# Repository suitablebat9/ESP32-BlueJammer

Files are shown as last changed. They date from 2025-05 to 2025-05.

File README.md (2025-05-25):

# ESP32-BlueJammer

**Bluetooth / BLE / WiFi / 2.4GHz Jamming Board**

The **ESP32-BlueJammer** is a compact, feature-rich board designed to disrupt devices operating on the 2.4GHz frequency band. Powered by an ESP32 and an nRF24 module, it generates noise and sends excessive packets to interfere with:

- Bluetooth audio and data connections  
- WiFi networks  
- BLE (Bluetooth Low Energy) devices  
- RC drones and remotes  
- IoT gadgets and more

> ⚠️ **Disclaimer:** This project is based entirely on the work of [Emensta](https://github.com/EmenstaNougat/ESP32-BlueJammer). I created this PCB to make their project more plug-and-play. All credit for the original firmware and research goes to them.

---

## 🔧 Features

- Toggleable on/off switch  
- Onboard momentary activation button  
- **`EXT Switch`** solder pads for external or wireless switch activation  
- **`EXT Power`** solder pads for external 5V power input  
  - (Polarity: **Left = GND**, **Right = 5V** with antennas facing away from you)  
- Combo firmware support – press the ESP32’s boot button while powered to cycle modes  
- **Blue jamming LED** shows active mode (can be disabled via jumper)  
- PH 2.0 battery connector (battery not included, connector provided)  
- USB Type-C power input on the board (not on the ESP32 directly)

---

## 🔄 LED Blink Mode Key

The **blue jamming LED** will blink to indicate the current active jamming mode on combo firmware:

- `1 blink` = **BT** (Bluetooth Classic)  
- `2 blinks` = **BLE** (Bluetooth Low Energy)  
- `3 blinks` = **WiFi**  
- `4 blinks` = **RC** (2.4GHz Drone/Remote)

The blink key is also printed on the right side of the board for quick reference.

---

## 🛰️ Mode Descriptions

| Mode | Description | Frequency Range |
|---|---|---|
| **BT 80CH** | Bluetooth Classic Jammer | 2.402 – 2.480 GHz |
| **BLE 40CH** | Bluetooth Low Energy Jammer | 2.400 – 2.4835 GHz |
| **BT-BLE 40-80CH** | Classic BT + BLE Combo Jammer | 2.400 – 2.4835 GHz |
| **BT-WiFi 14-80CH**| Classic BT + WiFi Combo Jammer | 2.400 – 2.4835 GHz |
| **WiFi 14CH** | WiFi Jammer | 2.400 – 2.4835 GHz |
| **2.4GHz All** | RC / Drone Jammer (CH 1–125) | 2.400 – 2.525 GHz |

---

## 🔌 Flashing the Firmware

You can easily flash your board using the browser-based [ESP32 BlueJammer Web Flasher](https://esp32-bluejammerflasher.pages.dev/) provided by Emensta.

### Steps:
1. Visit [ESP32-BlueJammerFlasher](https://esp32-bluejammerflasher.pages.dev/)
2. Choose the firmware type, "Generic"
3. Choose the firmware you want to flash
4. Connect your ESP32 via a data USB cable
5. Flash the firmware of your choice

> 💡 Tip: If flashing fails, make sure you’re using a data-capable USB cable and have the correct drivers installed for your ESP32.

---

## 🛒 Buy the Board

Want a fully assembled board? You can purchase one from my Tindie store here:  
👉 [PCB Studios on Tindie](https://www.tindie.com/products/pcb-studios/esp32-bluejammer/)

---

## 📦 What's Included

- Fully assembled **ESP32-BlueJammer PCB**
- PH 2.0 battery connector pre-installed
- Matching PH 2.0 connector for your battery (DIY soldering)
- Gerber files and schematic PDF (in this repo)

---

## ⚠️ Legal Notice

This project is for educational purposes only. Do not use this board to interfere with any wireless communications unless you have permission and are operating in a controlled, legal environment. You are solely responsible for what you do with this device.

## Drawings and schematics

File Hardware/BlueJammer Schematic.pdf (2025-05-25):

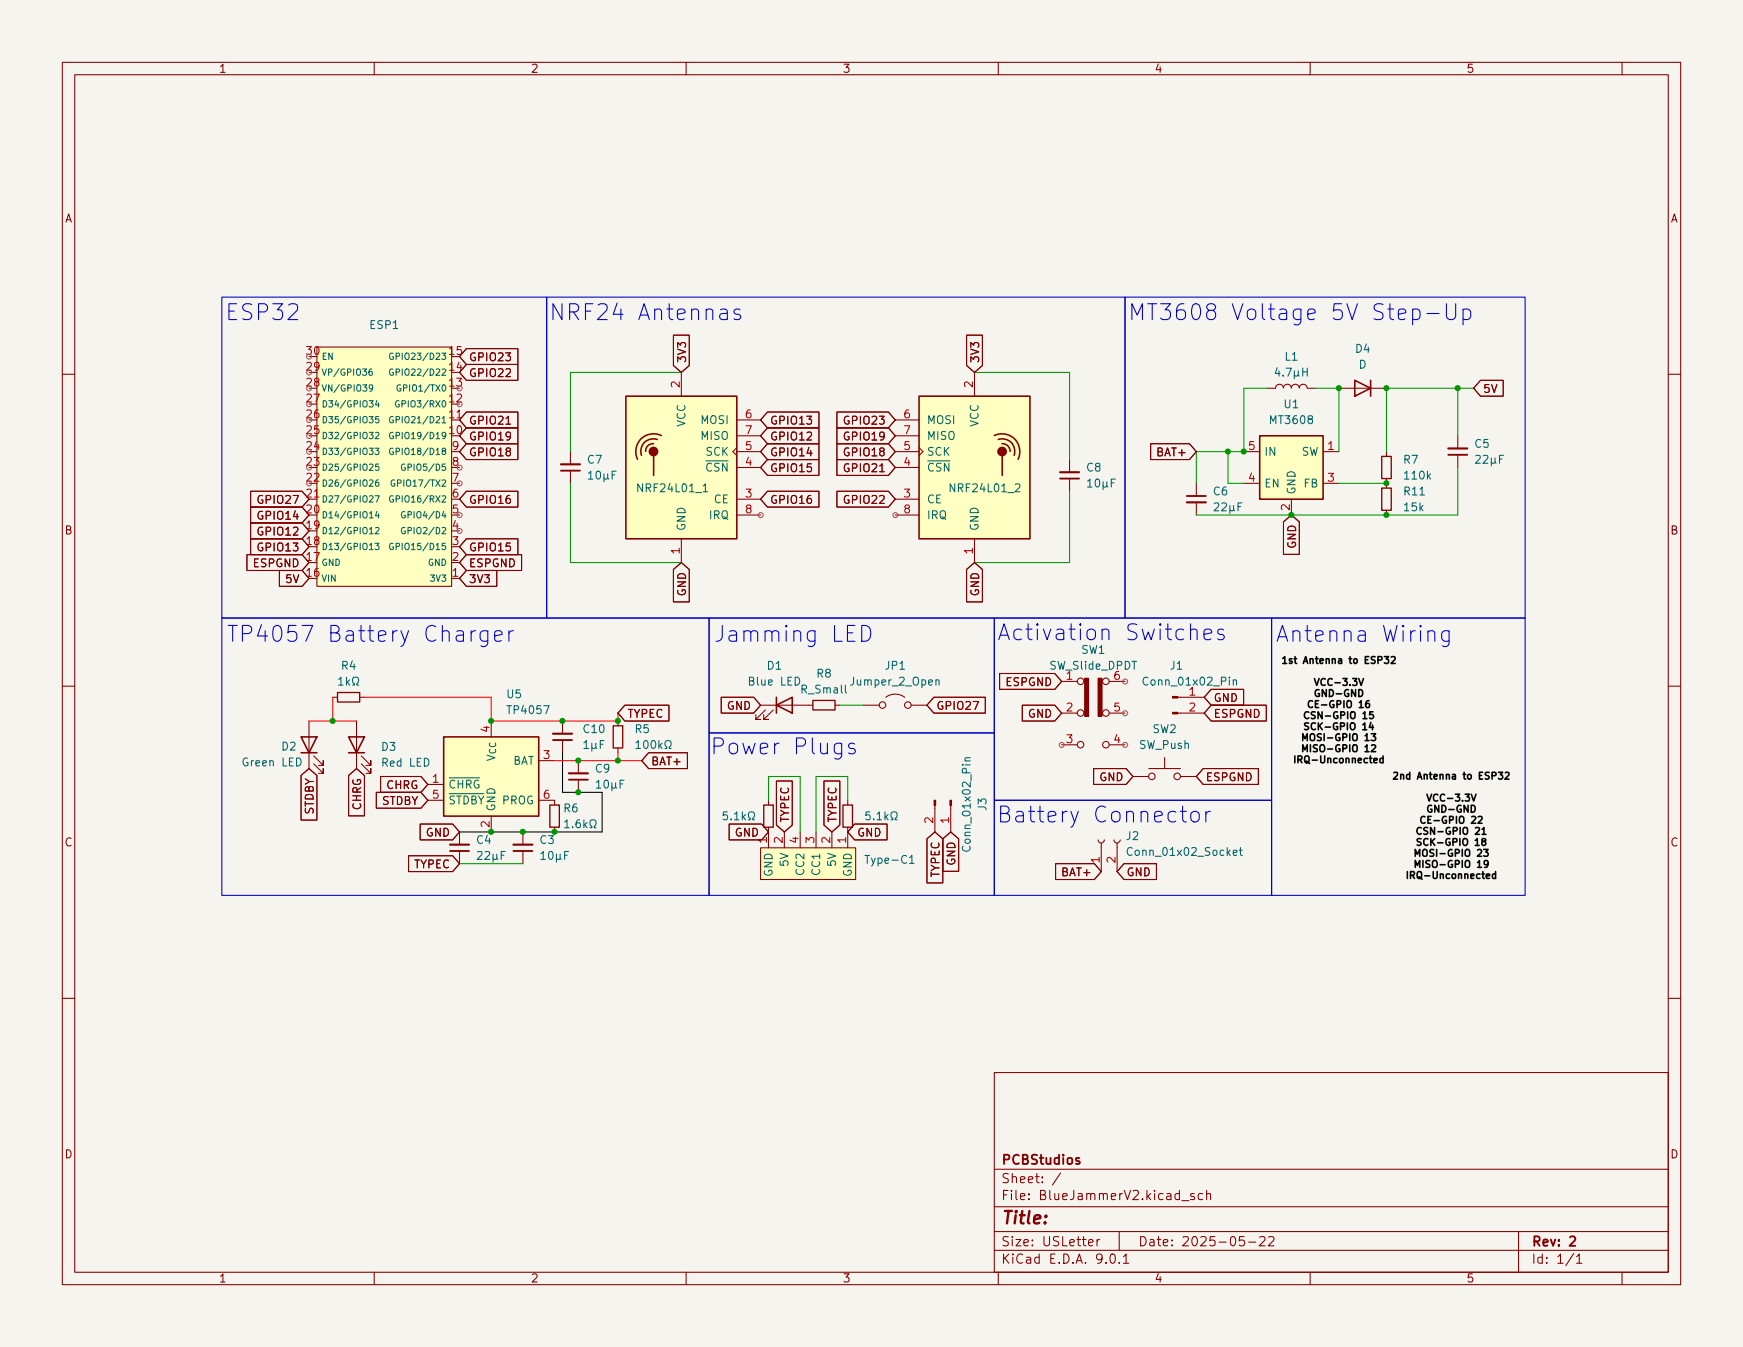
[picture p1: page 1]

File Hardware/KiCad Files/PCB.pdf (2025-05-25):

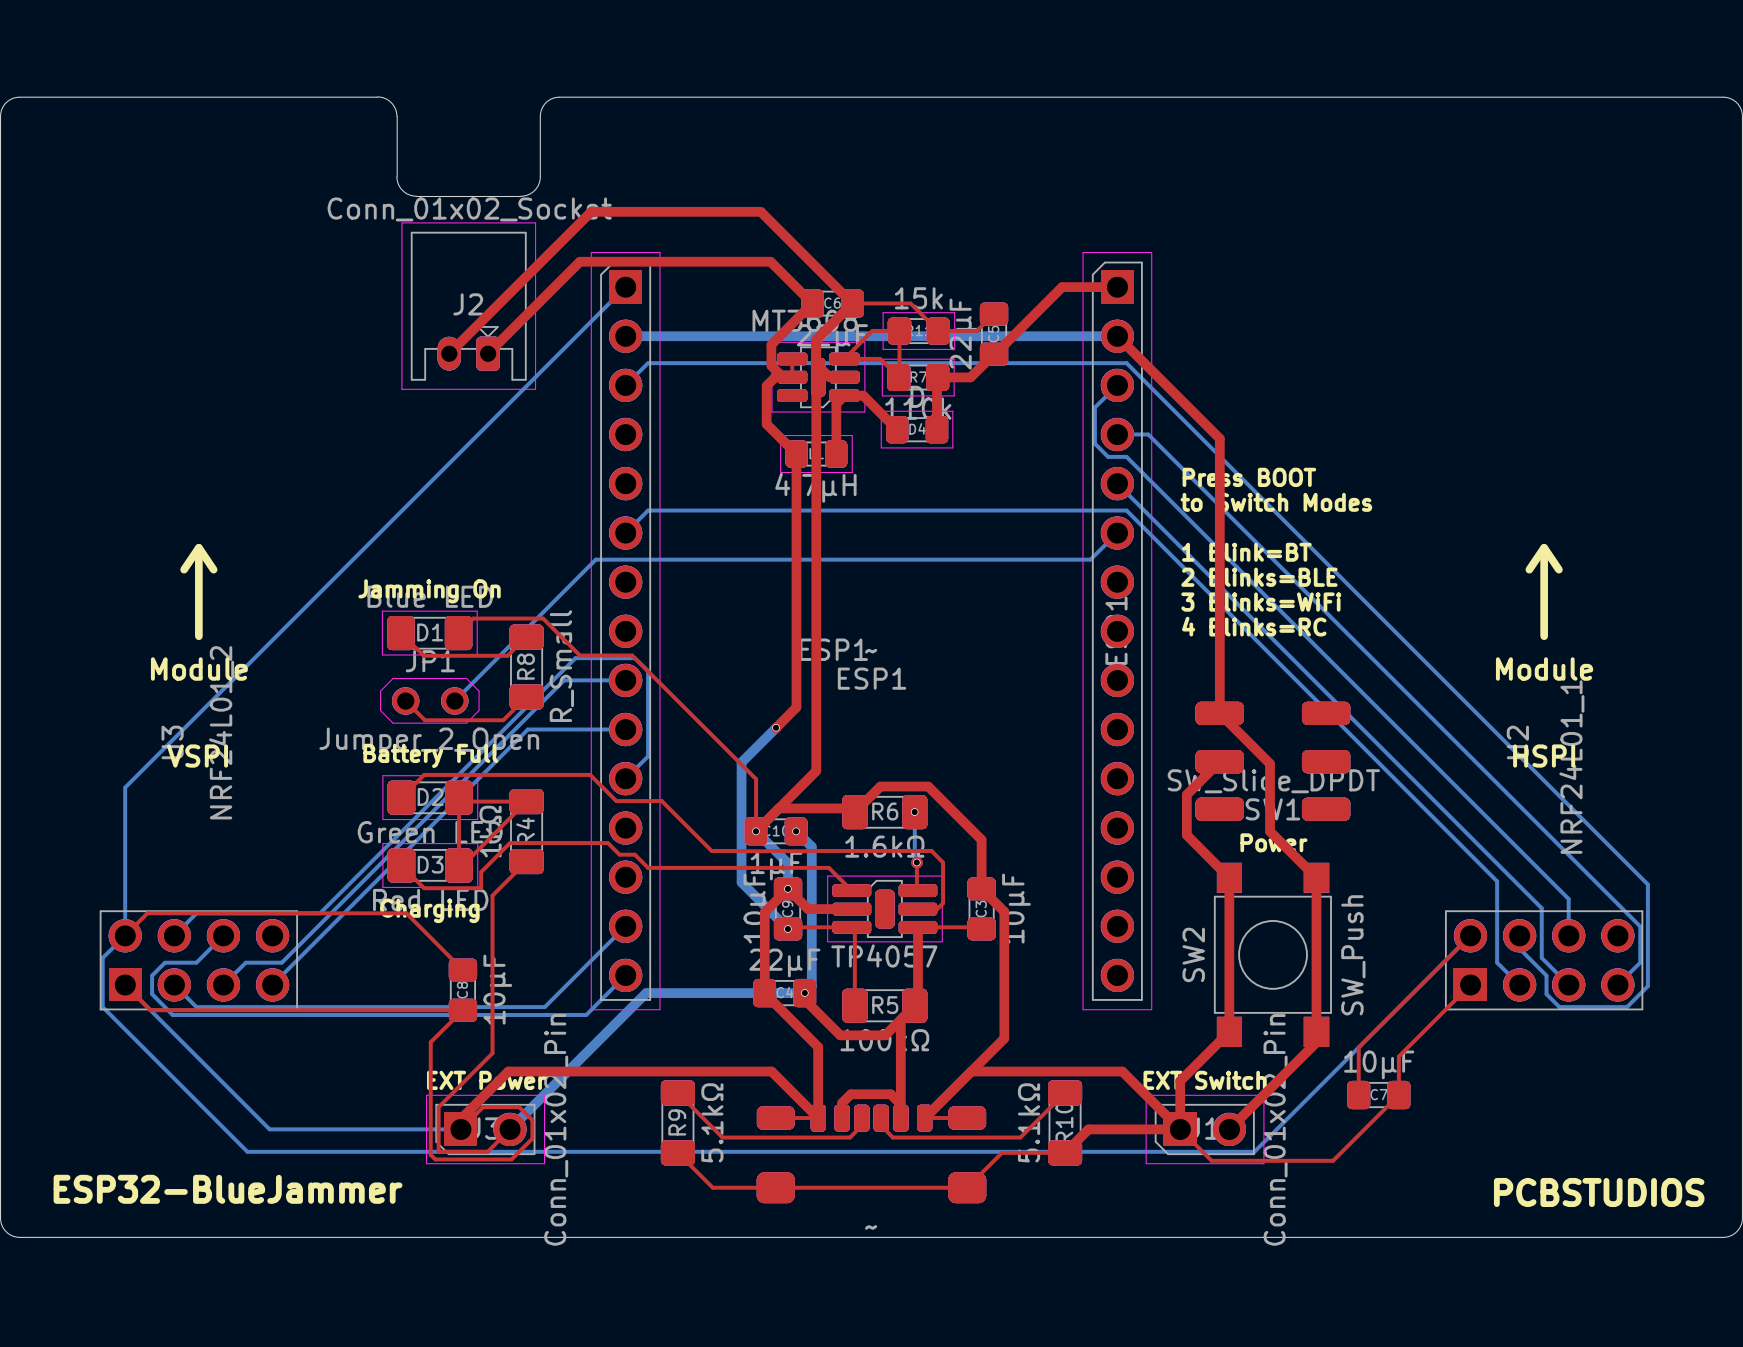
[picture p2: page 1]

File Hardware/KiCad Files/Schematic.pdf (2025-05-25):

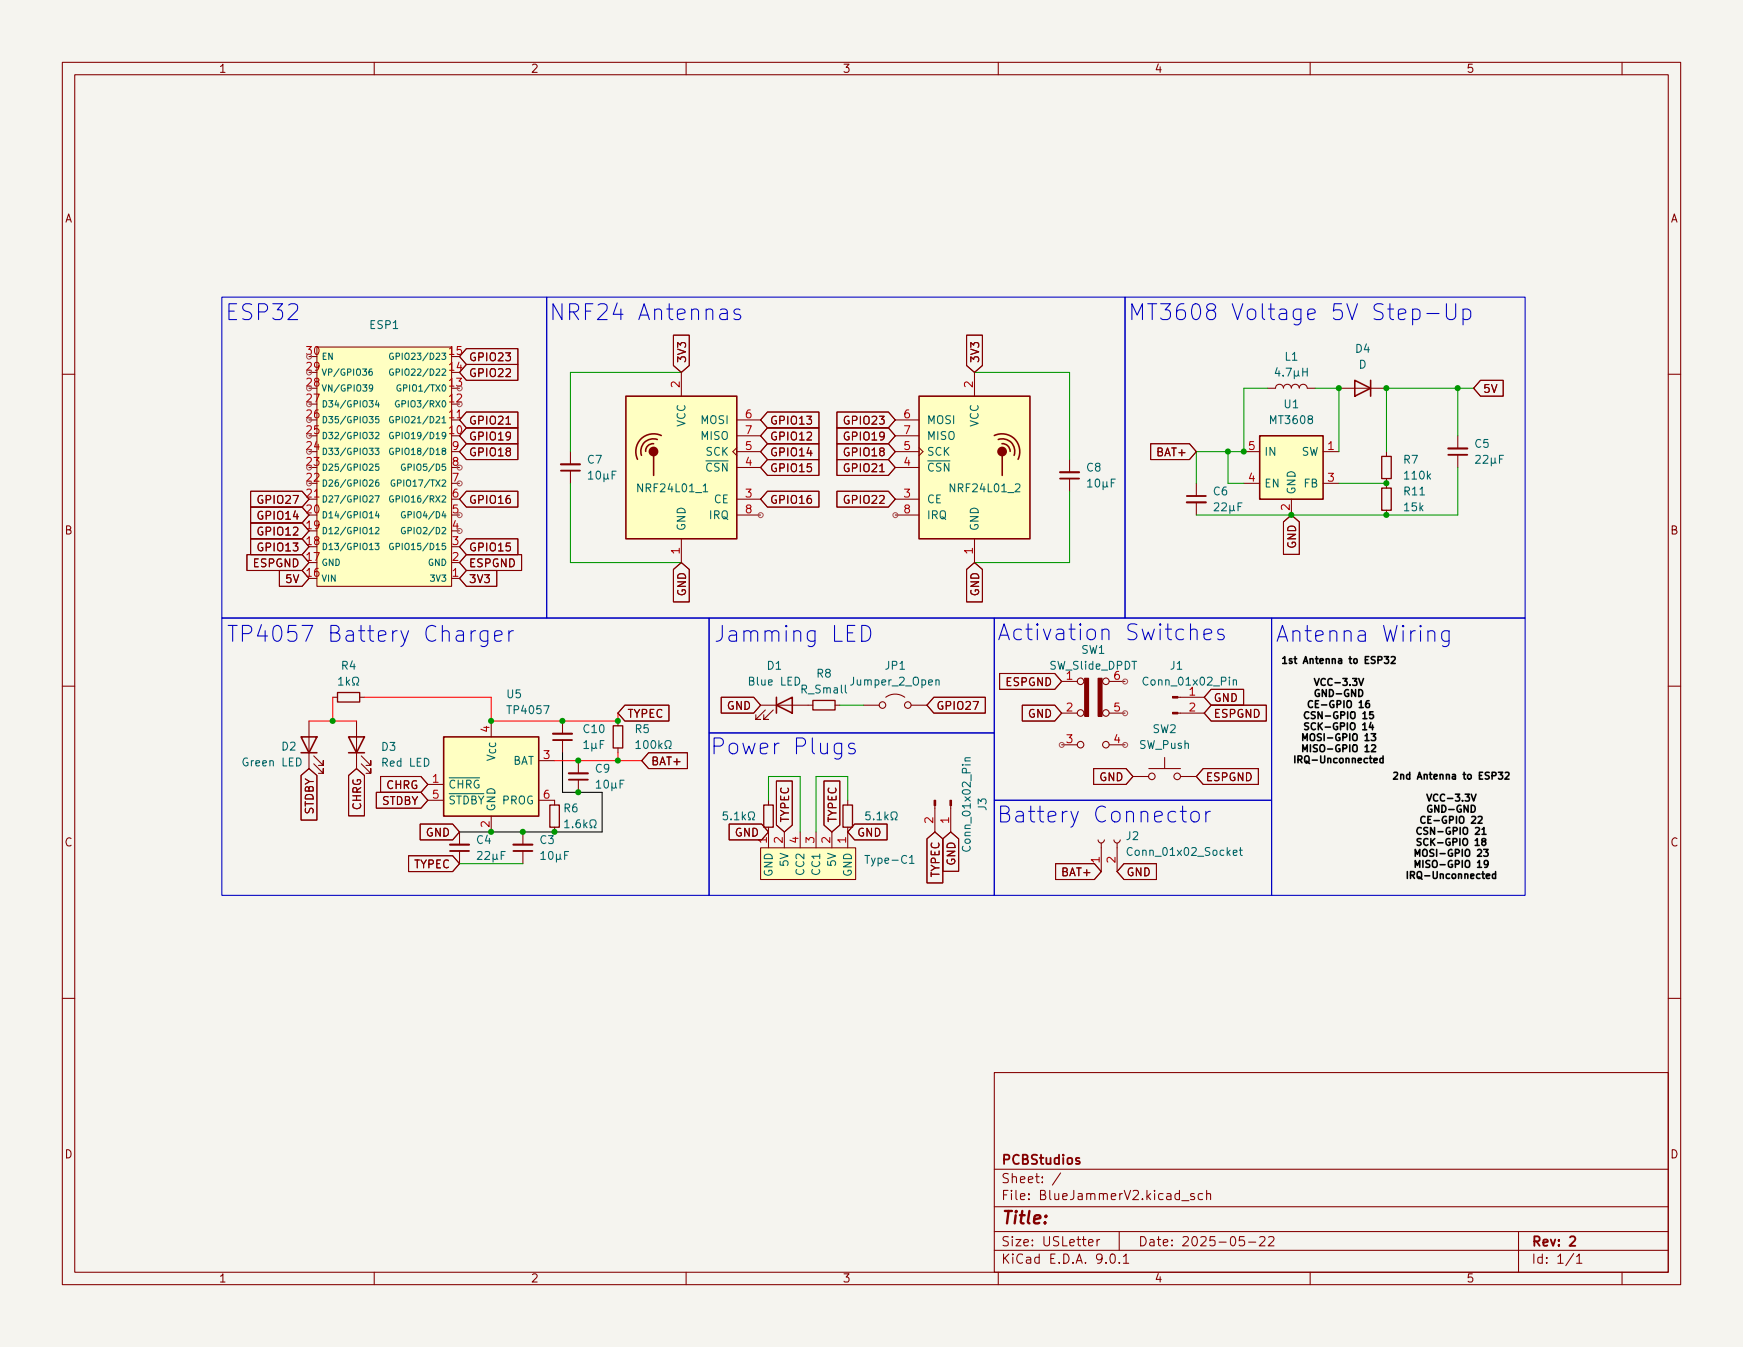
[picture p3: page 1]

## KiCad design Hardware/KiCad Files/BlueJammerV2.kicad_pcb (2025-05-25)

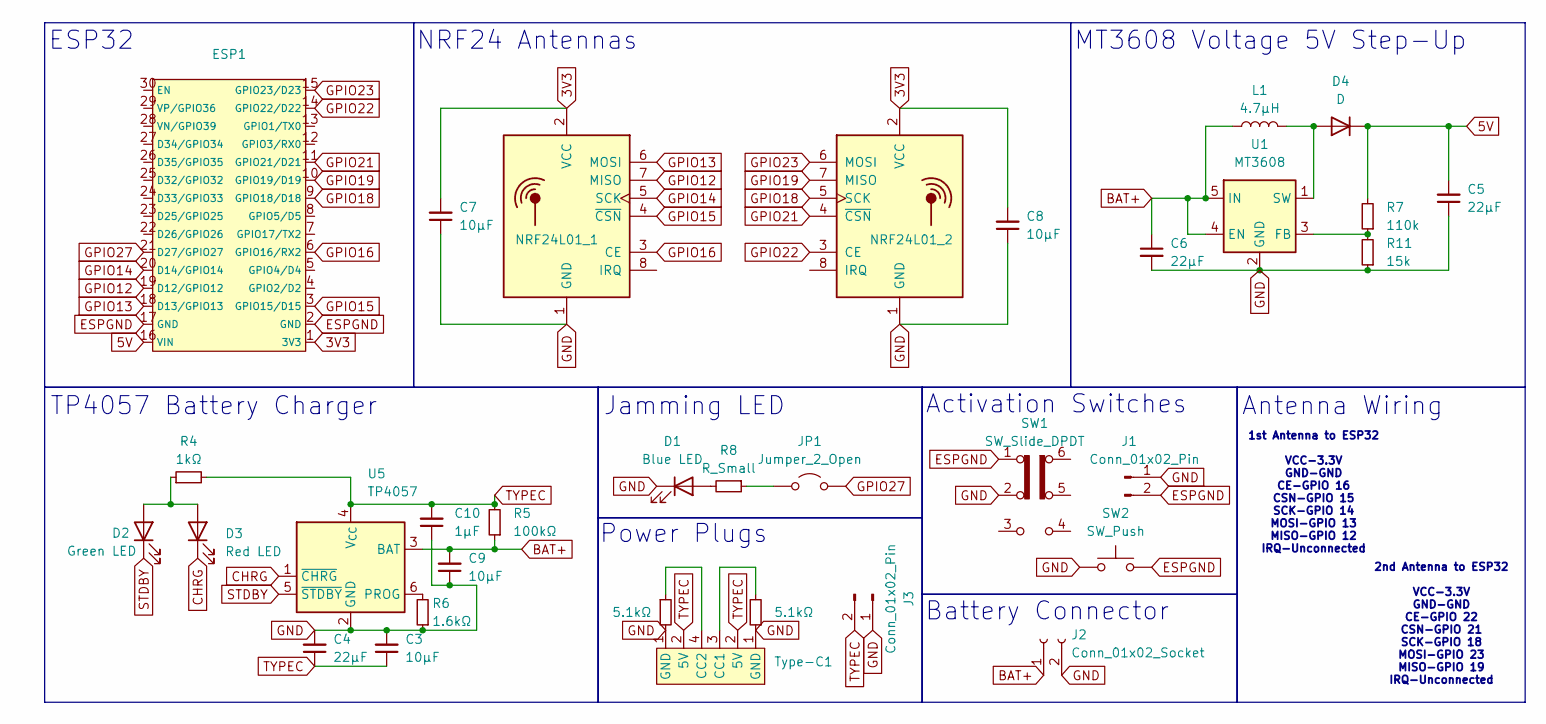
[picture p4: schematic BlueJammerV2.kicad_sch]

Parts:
C3, C7, C8, C9: 10µF; Cap_0805_2012Metric
C4, C5, C6: 22µF; Cap_0805_2012Metric
C10: 1µF; Cap_0805_2012Metric
D1: Blue LED; LED_1206_3216Metric_Pad1.42x1.75mm_HandSolder
D2: Green LED; LED_1206_3216Metric_Pad1.42x1.75mm_HandSolder
D3: Red LED; LED_1206_3216Metric_Pad1.42x1.75mm_HandSolder
D4: D; D_0805_2012Metric_Pad1.15x1.40mm_HandSolder
ESP1: 30 Pin ESP32 Dev Board
J1, J3: Conn_01x02_Pin; PinHeader_1x02_P2.54mm_Vertical
J2: Conn_01x02_Socket; JST_PH_S2B-PH-K_1x02_P2.00mm_Horizontal
JP1: Jumper_2_Open; TestPoint_2Pads_Pitch2.54mm_Drill0.8mm
L1: 4.7µH; L_0805_2012Metric_Pad1.15x1.40mm_HandSolder
R4: 1kΩ; R_1206_3216Metric
R5: 100kΩ; R_1206_3216Metric
R6: 1.6kΩ; R_1206_3216Metric
R7: 110k; R_0805_2012Metric_Pad1.20x1.40mm_HandSolder
R8: R_Small; R_1206_3216Metric
R9, R10: 5.1kΩ; R_1206_3216Metric
R11: 15k; R_0805_2012Metric_Pad1.20x1.40mm_HandSolder
SW1: SW_Slide_DPDT; MSS-22D18 Slide Switch
SW2: SW_Push; Button
Type-C1: SMD Type-C Port
U1: MT3608; SOT-23-6_Handsoldering
U2: NRF24L01_1; nRF24L01_Breakout
U3: NRF24L01_2; nRF24L01_Breakout
U5: TP4057; TSOT-23-6_HandSoldering

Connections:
3V3: C7.2, C8.2, ESP1.1 (3V3), U2.2 (VCC), U3.2 (VCC)
5V: C5.2, D4.1 (K), ESP1.16 (VIN), R7.2
BAT+: C6.1, C9.2, J2.1, L1.1, R5.1, U1.4 (EN), U1.5 (IN), U5.3 (BAT)
CHRG: D3.1 (K), U5.1 (~CHRG)
ESPGND: ESP1.2 (GND), ESP1.17 (GND), J1.2, SW1.1 (A), SW2.2
GND: C3.2, C4.2, C5.1, C6.2, C7.1, C8.1, C9.1, C10.1, D1.1 (K), J1.1, J2.2, J3.1, R6.1, R9.1, R10.2, R11.1, SW1.2 (B), SW2.1, Type-C1.1 (GND), U1.2 (GND), U2.1 (GND), U3.1 (GND), U5.2 (GND)
GPIO12: ESP1.19 (D12/GPIO12), U2.7 (MISO)
GPIO13: ESP1.18 (D13/GPIO13), U2.6 (MOSI)
GPIO14: ESP1.20 (D14/GPIO14), U2.5 (SCK)
GPIO15: ESP1.3 (GPIO15/D15), U2.4 (~CSN)
GPIO16: ESP1.6 (GPIO16/RX2), U2.3 (CE)
GPIO18: ESP1.9 (GPIO18/D18), U3.5 (SCK)
GPIO19: ESP1.10 (GPIO19/D19), U3.7 (MISO)
GPIO21: ESP1.11 (GPIO21/D21), U3.4 (~CSN)
GPIO22: ESP1.14 (GPIO22/D22), U3.3 (CE)
GPIO23: ESP1.15 (GPIO23/D23), U3.6 (MOSI)
GPIO27: ESP1.21 (D27/GPIO27), JP1.2 (B)
unnamed: D1.2 (A), R8.2
unnamed: D2.2 (A), D3.2 (A), R4.1
unnamed: D4.2 (A), L1.2, U1.1 (SW)
unnamed: JP1.1 (A), R8.1
unnamed: R9.2, Type-C1.3 (CC1)
unnamed: R10.1, Type-C1.4 (CC2)
unnamed: R7.1, R11.2, U1.3 (FB)
unnamed: R6.2, U5.6 (PROG)
STDBY: D2.1 (K), U5.5 (~STDBY)
TYPEC: C3.1, C4.1, C10.2, J3.2, R4.2, R5.2, Type-C1.2 (5V), U5.4 (V_{CC})

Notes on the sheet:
Jamming LED
1st Antenna to ESP32 VCC-3.3V GND-GND CE-GPIO 16 CSN-GPIO 15 SCK-GPIO 14 MOSI-GPIO 13 MISO-GPIO 12 IRQ-Unconnected
MT3608 Voltage 5V Step-Up
Power Plugs
ESP32
Activation Switches
TP4057 Battery Charger
NRF24 Antennas
Battery Connector
2nd Antenna to ESP32 VCC-3.3V GND-GND CE-GPIO 22 CSN-GPIO 21 SCK-GPIO 18 MOSI-GPIO 23 MISO-GPIO 19 IRQ-Unconnected
Antenna Wiring

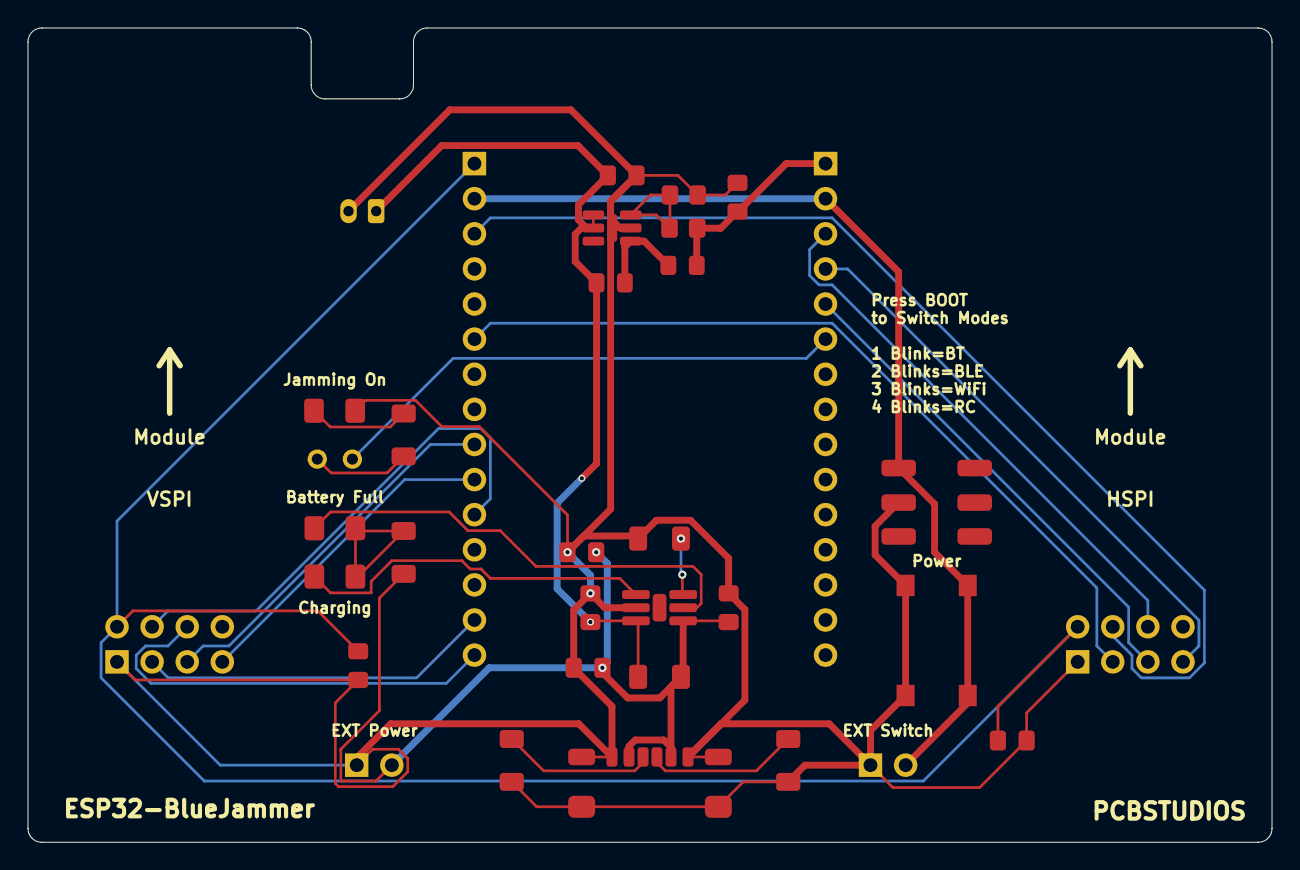
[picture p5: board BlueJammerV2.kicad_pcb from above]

Board: 2 copper layers, 90.0 x 58.9 mm, 33 parts (0 on the bottom side), 27 nets.
